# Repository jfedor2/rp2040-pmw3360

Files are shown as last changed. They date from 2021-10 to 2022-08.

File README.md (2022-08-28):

# RP2040+PMW3360

This repository contains design files and code for a PCB carrying Raspberry Pi's RP2040 chip and the PixArt PMW3360 optical mouse sensor. They can be used for rapid prototyping of USB mice and trackballs.

The files in the [fabrication](fabrication) folder can be used to order this board from JLCPCB with SMT assembly. The board you get includes everything except the sensor. If some of the specific components are out of stock, try to find an equivalent with the same package and parameters.

The sensor chip should be soldered on the bottom side (the opposite side from all the other components). The dot marks pin 1. The optic goes on the top side.

If you're looking for a convenient way of mounting mouse button switches in a case, perhaps [this repository](https://github.com/jfedor2/mouse-switch-mount-pcb) will be of use.

Examples of devices made using this board:

* [Trackball 7](https://www.prusaprinters.org/prints/83631-trackball-7)
* [Trackball 8](https://www.prusaprinters.org/prints/84148-trackball-8)
* [Spherical trackball](https://www.prusaprinters.org/prints/85053-spherical-trackball)
* [Two-ball trackball](https://github.com/jfedor2/two-ball-trackball)
* [Mouse 1](https://www.prusaprinters.org/prints/87379-mouse-1)
* [Mouse 2](https://www.prusaprinters.org/prints/88403-mouse-2)
* [Trackball with twist-to-scroll](https://github.com/jfedor2/twist-to-scroll-trackball)
* [Trackball with scroll ring](https://github.com/jfedor2/scroll-ring-trackball)
* [Mouse 4](https://www.prusaprinters.org/prints/127451-mouse-4)
* [Trackball 15](https://www.prusaprinters.org/prints/131450-trackball-15), [15b/c](https://www.printables.com/model/263616-trackball-15bc), [15d/e](https://www.printables.com/model/267954-trackball-15de)

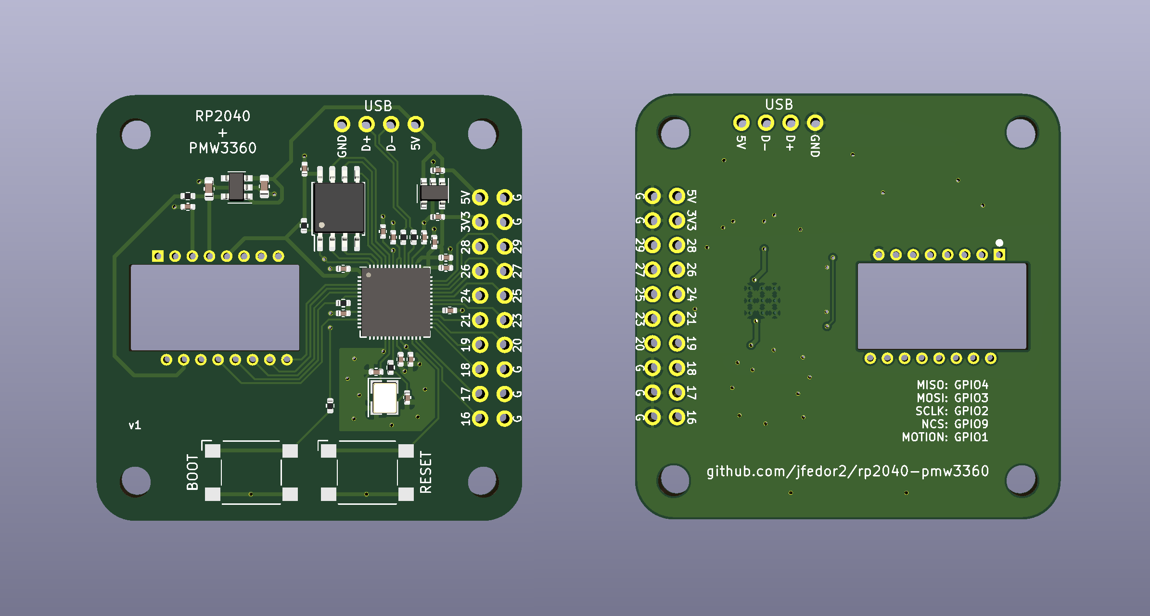
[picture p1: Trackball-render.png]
PCB render


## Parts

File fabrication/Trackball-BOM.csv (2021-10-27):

Comment | Designator | Footprint | LCSC
0.1u | C11 | Capacitor_SMD:C_0603_1608Metric | C14663
1u | C12 | Capacitor_SMD:C_0603_1608Metric | C15849
4.7u | C14 | Capacitor_SMD:C_0402_1005Metric | C23733
1u | C10,C13,C15,C16 | Capacitor_SMD:C_0402_1005Metric | C52923
30p | C18,C19 | Capacitor_SMD:C_0402_1005Metric | C1570
100n | C1,C2,C3,C4,C5,C6,C7,C8,C9,C17 | Capacitor_SMD:C_0402_1005Metric | C1525
MountingHole | H1,H2,H3,H4 | MountingHole:MountingHole_3.2mm_M3
Conn_01x04 | J1 | Connector_PinHeader_2.54mm:PinHeader_1x04_P2.54mm_Vertical
Conn_02x10_Odd_Even | J2 | Connector_PinHeader_2.54mm:PinHeader_2x10_P2.54mm_Vertical
39 | R1 | Resistor_SMD:R_0402_1005Metric | C25110
27 | R3,R4 | Resistor_SMD:R_0402_1005Metric | C138021
10k | R2,R5 | Resistor_SMD:R_0402_1005Metric | C25744
1k | R6,R7 | Resistor_SMD:R_0402_1005Metric | C11702
SW_Push | SW1,SW2 | Button_Switch_SMD:SW_SPST_Omron_B3FS-100xP | C271750
TCR2EF19 | U1 | Package_TO_SOT_SMD:SOT-23-5 | C146366
PMW3360 | U2 | PMW3360:PMW3360
RP2040 | U3 | RP2040:RP2040-QFN-56 | C2040
TLV73333PDBV | U4 | Package_TO_SOT_SMD:SOT-23-5 | C134139
W25Q128JVS | U5 | Package_SO:SOIC-8_5.23x5.23mm_P1.27mm | C97521
Crystal_GND24 | Y1 | Crystal:Crystal_SMD_3225-4Pin_3.2x2.5mm | C9002

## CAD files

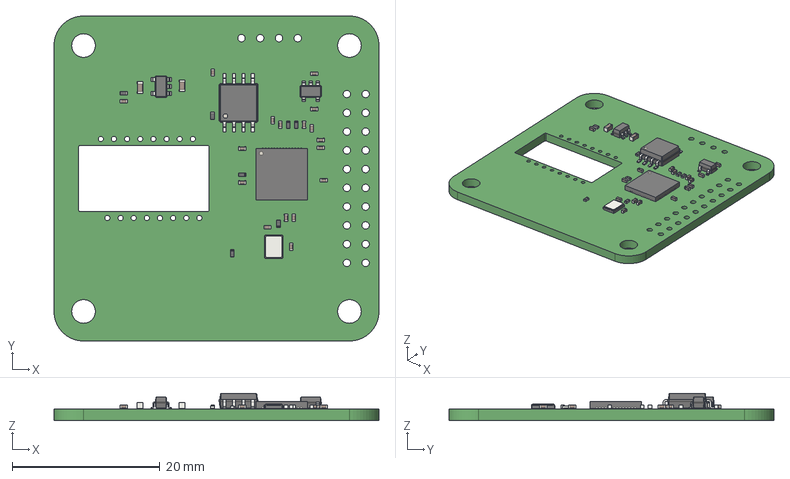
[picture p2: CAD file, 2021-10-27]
Trackball.step
44.0 x 44.0 x 3.71 mm

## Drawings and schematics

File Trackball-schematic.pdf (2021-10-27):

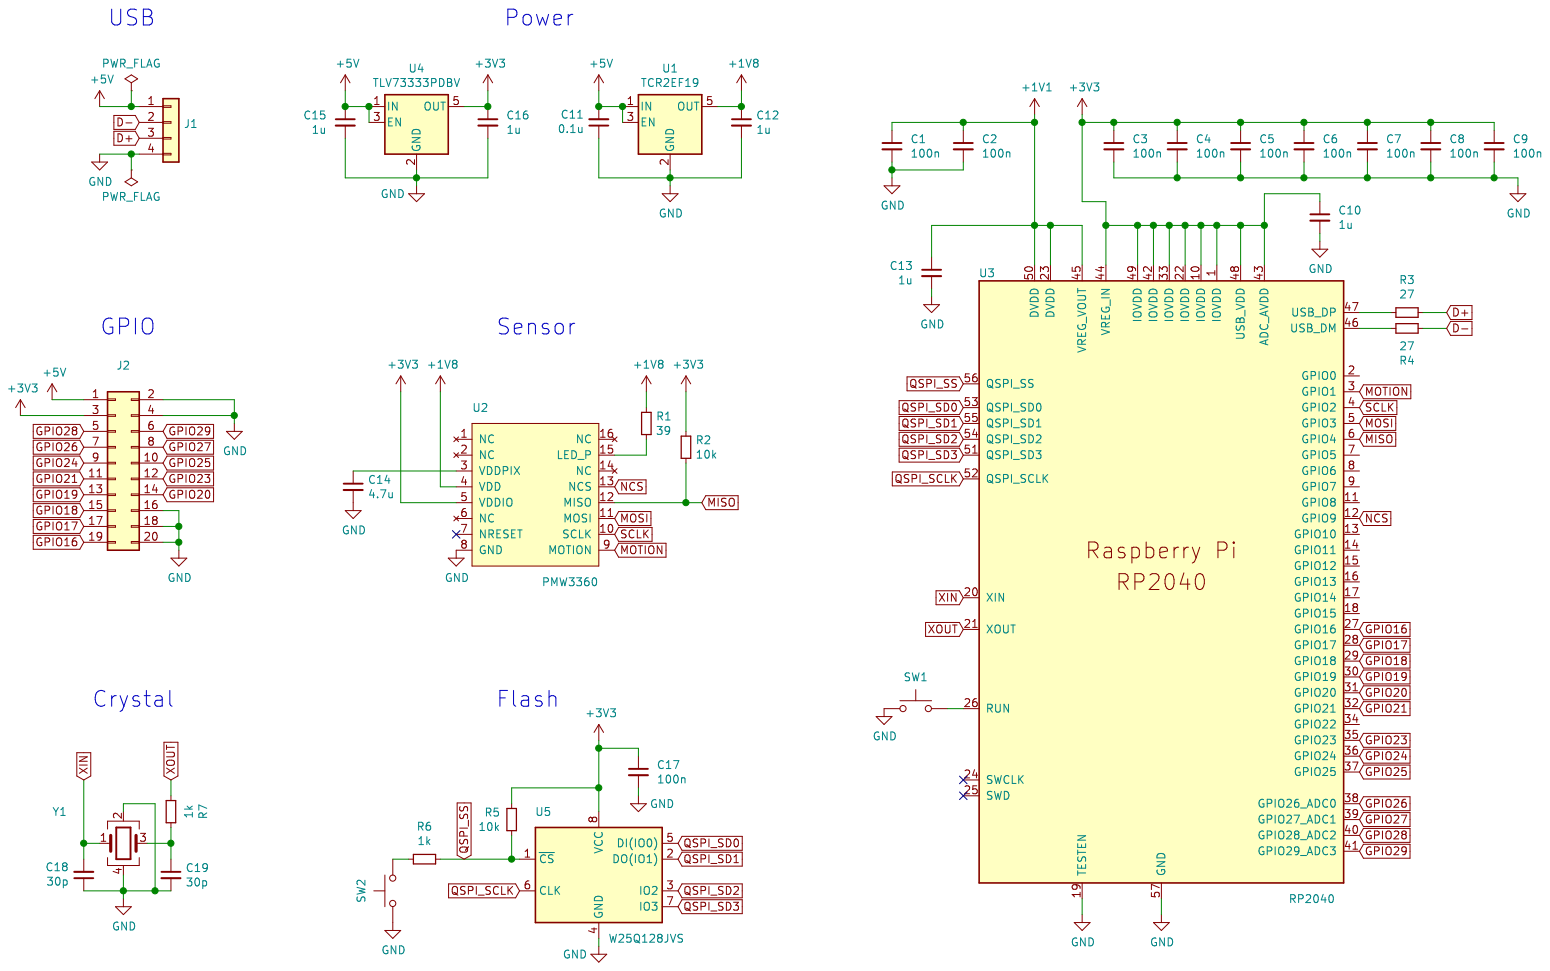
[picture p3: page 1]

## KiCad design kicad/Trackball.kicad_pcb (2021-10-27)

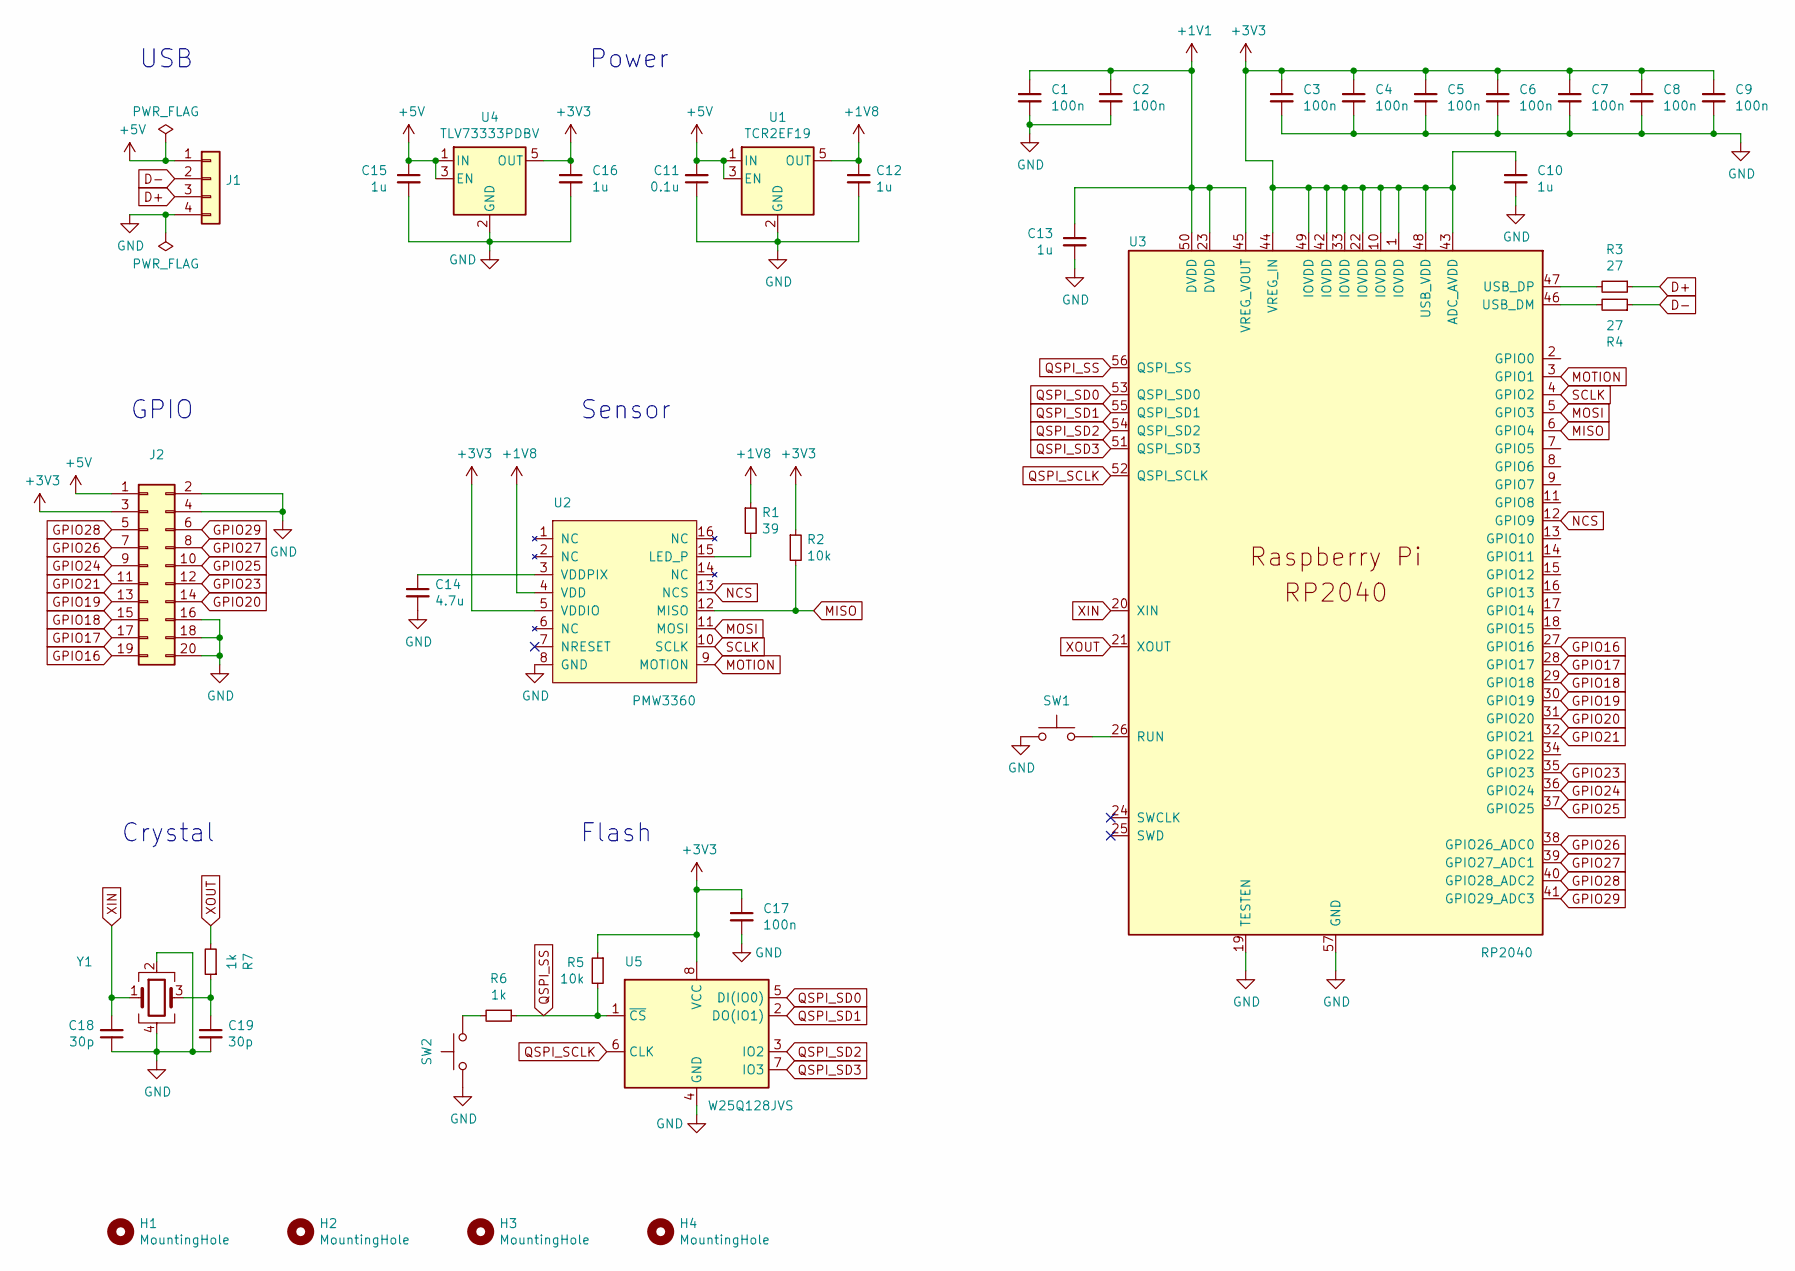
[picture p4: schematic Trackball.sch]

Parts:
C1, C2, C3, C4, C5, C6, C7, C8, C9, C17: 100n; C_0402_1005Metric; LCSC C1525
C10, C13, C15, C16: 1u; C_0402_1005Metric; LCSC C52923
C11: 0.1u; C_0603_1608Metric; LCSC C14663
C12: 1u; C_0603_1608Metric; LCSC C15849
C14: 4.7u; C_0402_1005Metric; LCSC C23733
C18, C19: 30p; C_0402_1005Metric; LCSC C1570
H1, H2, H3, H4: MountingHole; MountingHole_3.2mm_M3
J1: Conn_01x04; PinHeader_1x04_P2.54mm_Vertical
J2: Conn_02x10_Odd_Even; PinHeader_2x10_P2.54mm_Vertical
R1: 39; R_0402_1005Metric; LCSC C25110
R2, R5: 10k; R_0402_1005Metric; LCSC C25744
R3, R4: 27; R_0402_1005Metric; LCSC C138021
R6, R7: 1k; R_0402_1005Metric; LCSC C11702
SW1, SW2: SW_Push; SW_SPST_Omron_B3FS-100xP; LCSC C271750
U1: TCR2EF19; SOT-23-5; LCSC C146366
U2: PMW3360
U3: RP2040; RP2040-QFN-56; LCSC C2040
U4: TLV73333PDBV; SOT-23-5; LCSC C134139
U5: W25Q128JVS; SOIC-8_5.23x5.23mm_P1.27mm; LCSC C97521
Y1: Crystal_GND24; Crystal_SMD_3225-4Pin_3.2x2.5mm; LCSC C9002

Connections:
+1V1: C1.1, C2.1, C13.1, U3.23 (DVDD), U3.45 (VREG_VOUT), U3.50 (DVDD)
+1V8: C12.1, R1.1, U1.5 (OUT), U2.4 (VDD)
+3V3: C3.1, C4.1, C5.1, C6.1, C7.1, C8.1, C9.1, C10.1, C16.1, C17.1, J2.3, R2.1, R5.1, U2.5 (VDDIO), U3.1 (IOVDD), U3.10 (IOVDD), U3.22 (IOVDD), U3.33 (IOVDD), U3.42 (IOVDD), U3.43 (ADC_AVDD), U3.44 (VREG_IN), U3.48 (USB_VDD), U3.49 (IOVDD), U4.5 (OUT), U5.8 (VCC)
+5V: C11.2, C15.1, J1.1, J2.1, U1.1 (IN), U1.3 (EN), U4.1 (IN), U4.3 (EN)
D+: J1.3, R3.1
D-: J1.2, R4.1
GND: C1.2, C2.2, C3.2, C4.2, C5.2, C6.2, C7.2, C8.2, C9.2, C10.2, C11.1, C12.2, C13.2, C14.2, C15.2, C16.2, C17.2, C18.1, C19.2, J1.4, J2.2, J2.4, J2.16, J2.18, J2.20, SW1.1, SW2.1, U1.2 (GND), U2.8 (GND), U3.19 (TESTEN), U3.57 (GND), U4.2 (GND), U5.4 (GND), Y1.2, Y1.4
GPIO16: J2.19, U3.27 (GPIO16)
GPIO17: J2.17, U3.28 (GPIO17)
GPIO18: J2.15, U3.29 (GPIO18)
GPIO19: J2.13, U3.30 (GPIO19)
GPIO20: J2.14, U3.31 (GPIO20)
GPIO21: J2.11, U3.32 (GPIO21)
GPIO23: J2.12, U3.35 (GPIO23)
GPIO24: J2.9, U3.36 (GPIO24)
GPIO25: J2.10, U3.37 (GPIO25)
GPIO26: J2.7, U3.38 (GPIO26_ADC0)
GPIO27: J2.8, U3.39 (GPIO27_ADC1)
GPIO28: J2.5, U3.40 (GPIO28_ADC2)
GPIO29: J2.6, U3.41 (GPIO29_ADC3)
MISO: R2.2, U2.12 (MISO), U3.6 (GPIO4)
MOSI: U2.11 (MOSI), U3.5 (GPIO3)
MOTION: U2.9 (MOTION), U3.3 (GPIO1)
NCS: U2.13 (NCS), U3.12 (GPIO9)
unnamed: C14.1, U2.3 (VDDPIX)
unnamed: C19.1, R7.1, Y1.3
unnamed: R1.2, U2.15 (LED_P)
unnamed: R3.2, U3.47 (USB_DP)
unnamed: R4.2, U3.46 (USB_DM)
unnamed: R6.2, SW2.2
unnamed: SW1.2, U3.26 (RUN)
QSPI_SCLK: U3.52 (QSPI_SCLK), U5.6 (CLK)
QSPI_SD0: U3.53 (QSPI_SD0), U5.5 (DI(IO0))
QSPI_SD1: U3.55 (QSPI_SD1), U5.2 (DO(IO1))
QSPI_SD2: U3.54 (QSPI_SD2), U5.3 (IO2)
QSPI_SD3: U3.51 (QSPI_SD3), U5.7 (IO3)
QSPI_SS: R5.2, R6.1, U3.56 (QSPI_SS), U5.1 (~CS)
SCLK: U2.10 (SCLK), U3.4 (GPIO2)
XIN: C18.2, U3.20 (XIN), Y1.1
XOUT: R7.2, U3.21 (XOUT)

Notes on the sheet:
Crystal
Power
USB
Flash
GPIO
Sensor

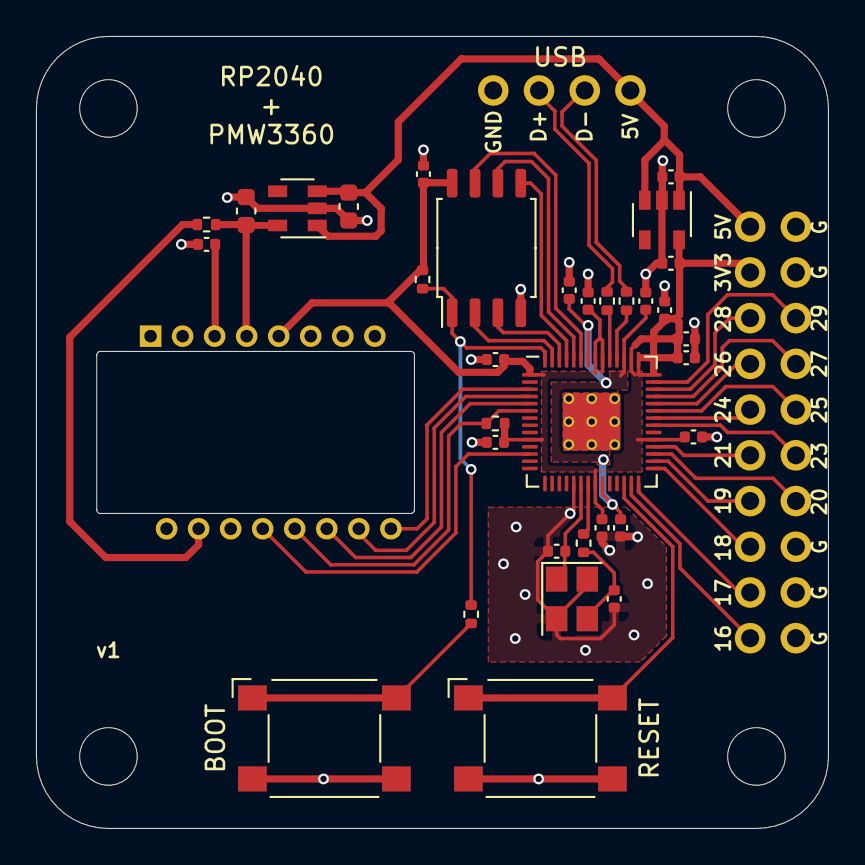
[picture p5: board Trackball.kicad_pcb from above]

Board: 2 copper layers, 44.0 x 44.0 mm, 40 parts (1 on the bottom side), 40 nets.

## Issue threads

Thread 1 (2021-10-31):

A few parts appear to be in the wrong orientation for pcba

mrlinuxfish, 2021-10-31:
When I try to order from jlcpcb, a few of the parts look like they're loading in the assembly the wrong way around

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

jfedor2, 2021-10-31:
Yeah, that's normal with files exported from KiCad. I guess there's more than one convention when it comes to the part orientation and JLCPCB uses a different one. Might be worth fixing, but it's not a problem when ordering PCBs from them (I've done it with these exact files). What happens is a human looks at the files and fixes the orientations before the PCBs are fabricated.

mrlinuxfish, 2021-10-31:
Awesome, as long as they get produced correctly there shouldn't be any problem

Closed 2021-10-31.

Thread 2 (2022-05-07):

add pullup resistors to increase switch life.

itsnoteasy, 2022-05-07:
I think that you could add a 3.3k pullup to 3.3v on each button header. this would prevent the double click bug from occuirng by providing at least 1milliamp wetting current to blow through the oxide on the switch. this is specified in the omron datasheet as required to ensure reliable operation.

there's a boring video here about it. https://www.youtube.com/watch?v=v5BhECVlKJA

Closed 2022-05-16.

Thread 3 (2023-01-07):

cheaper assembly  suggestion

itsnoteasy, 2023-01-07:
i'm about to order this but was horrified at the expense of the extended components which require adding a reel for a fee of around 6 euro per reel last time i checked. the csv and bom file generation was beyond me so i'm gonna put up with it. here's a few suggestions anyway.

replace r1 39 ohm resistor with a pair of resistors 49.9ohm and 180ohm in parallel for 39.3ohm these can be sourced in 0603 size.
likewise replace r3 and r4 with a larger size.
remove sw1 and sw2, these can be hand soldered.
I have edited the bom and csv of the last two and shaved 5 euro off my order. i cannot easily change the 39 ohm resistor.
i won't complain about the voltage regulators because they are an ephemeral purchase, but come on, 5 euro for a resistor is far too expensive.

itsnoteasy, 2023-02-16:
If you like then you can break out GPIO0 beside GPIO1(motion). this would allow the pcb to be reused as a hid-remapper, although the existing pcb should be able to make a dual rp2040 version.

jfedor2, 2023-02-18:
You should be able to use the board for HID Remapper as is, the pins used for the USB interface are configurable. You'd have to recompile the firmware.

itsnoteasy, 2023-02-18:
I figured as much but i made this issue as a way to track improvements if anyone was to make another version down the line.

Closed 2023-02-18.

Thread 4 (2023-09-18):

pico/time.h missing in pmw3360.c

FredNov, 2023-09-18:
Tried to build the code and got a warning
warning: implicit declaration of function 'sleep_us'

It seems like you need to include in pmw3360.c
#include <pico/time.h>

BTW Really great project

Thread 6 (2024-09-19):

Flashing Instructions

dahmwern, 2024-09-19:
Can you provide some flashing instructions for the PCB and sensor? I'm seeing multiple sets of .c and .h files. It would be helpful if you could shed some light into what needs to be flashed or configured here. Any help would be greatly appreciated!

My PCB is being assembled now and trackball housing design is being finalized before printing.

jfedor2, 2024-09-19:
Press and hold the BOOT button and while holding it, press and release the RESET button.

A drive named "RPI-RP2" will appear on your computer. Copy the UF2 file to it.

dahmwern, 2024-09-20:
I spent too much time looking at the code files, and missed the .uf2! Thanks!

Closed 2024-09-20.

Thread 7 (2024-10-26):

how to adjust lift off distance?

dahmwern, 2024-10-26:
Can you provide guidance on the correct way to adjust lift off distance in the code?

jfedor2, 2024-10-26:
From what I can see in the datasheet you can choose between 2 and 3 mm by writing those values to register Lift_Config (0x63).

There's also some calibration procedure, but I never tried it.

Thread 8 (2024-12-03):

Mousebuttons not recognized for libinput autoscroll binding.

slm85kbh, 2024-12-03:
Activating "Press left and right buttons for middle-click" for autoscrolling in libinput (KDE 6, Arch Linux) does not work for me.
It works on my regular Logitech MX Master 2S.

Both buttons work as they should as left/right buttons otherwise.
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

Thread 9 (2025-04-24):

Does this PCB support QMK firmware?

619frank, 2025-04-24:

jfedor2, 2025-04-24:
I haven't tried, but if QMK runs on RP2040 and supports the PMW3360 sensor then I don't see why it wouldn't work.

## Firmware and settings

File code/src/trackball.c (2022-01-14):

/* 
 * The MIT License (MIT)
 *
 * Copyright (c) 2021 Jacek Fedorynski
 * Copyright (c) 2019 Ha Thach (tinyusb.org)
 *
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
 */

#include <stdlib.h>
#include <stdio.h>
#include <string.h>

#include "bsp/board.h"
#include "tusb.h"

#include "pico/stdlib.h"

#include "hardware/gpio.h"

#include "pmw3360.h"

#define PIN_LMB 16
#define PIN_RMB 17

// These IDs are bogus. If you want to distribute any hardware using this,
// you will have to get real ones.
#define USB_VID 0xCAFE
#define USB_PID 0xBABA

tusb_desc_device_t const desc_device = {
    .bLength = sizeof(tusb_desc_device_t),
    .bDescriptorType = TUSB_DESC_DEVICE,
    .bcdUSB = 0x0200,
    .bDeviceClass = 0x00,
    .bDeviceSubClass = 0x00,
    .bDeviceProtocol = 0x00,
    .bMaxPacketSize0 = CFG_TUD_ENDPOINT0_SIZE,

    .idVendor = USB_VID,
    .idProduct = USB_PID,
    .bcdDevice = 0x0100,

    .iManufacturer = 0x01,
    .iProduct = 0x02,
    .iSerialNumber = 0x00,

    .bNumConfigurations = 0x01
};

uint8_t const desc_hid_report[] = {
    0x05, 0x01,                 // USAGE_PAGE (Generic Desktop)
    0x09, 0x02,                 // USAGE (Mouse)
    0xa1, 0x01,                 // COLLECTION (Application)
    0x09, 0x01,                 //   USAGE (Pointer)
    0xA1, 0x00,                 //   COLLECTION (Physical)
//  0x85, 0x01,                 //     REPORT_ID (1)
    0x05, 0x09,                 //     USAGE_PAGE (Button)
    0x19, 0x01,                 //     USAGE_MINIMUM (1)
    0x29, 0x03,                 //     USAGE_MAXIMUM (3)
    0x15, 0x00,                 //     LOGICAL_MINIMUM (0)
    0x25, 0x01,                 //     LOGICAL_MAXIMUM (1)
    0x95, 0x03,                 //     REPORT_COUNT (3)
    0x75, 0x01,                 //     REPORT_SIZE (1)
    0x81, 0x02,                 //     INPUT (Data,Var,Abs)
    0x95, 0x01,                 //     REPORT_COUNT (1)
    0x75, 0x05,                 //     REPORT_SIZE (5)
    0x81, 0x03,                 //     INPUT (Const,Var,Abs)
    0x05, 0x01,                 //     USAGE_PAGE (Generic Desktop)
    0x09, 0x30,                 //     USAGE (X)
    0x09, 0x31,                 //     USAGE (Y)
    0x16, 0x00, 0x80,           //     LOGICAL_MINIMUM(-32768)
    0x26, 0xff, 0x7f,           //     LOGICAL_MAXIMUM(32767)
    0x75, 0x10,                 //     REPORT_SIZE (16)
    0x95, 0x02,                 //     REPORT_COUNT (2)
    0x81, 0x06,                 //     INPUT (Data,Var,Rel)
    0xC0,                       //   END_COLLECTION
    0xC0,                       // END COLLECTION
};

#define CONFIG_TOTAL_LEN (TUD_CONFIG_DESC_LEN + TUD_HID_DESC_LEN)
#define EPNUM_HID 0x81

uint8_t const desc_configuration[] = {
    // Config number, interface count, string index, total length, attribute, power in mA
    TUD_CONFIG_DESCRIPTOR(1, 1, 0, CONFIG_TOTAL_LEN, 0, 100),

    // Interface number, string index, protocol, report descriptor len, EP In address, size & polling interval
    TUD_HID_DESCRIPTOR(0, 0, HID_ITF_PROTOCOL_NONE, sizeof(desc_hid_report), EPNUM_HID, CFG_TUD_HID_EP_BUFSIZE, 1)
};

char const *string_desc_arr[] = {
    (const char[]) {0x09, 0x04},        // 0: is supported language is English (0x0409)
    "Trackball",                // 1: Manufacturer
    "Trackball",                // 2: Product
};

// HID report
typedef struct __attribute__ ((packed)) {
    uint8_t buttons;
    int16_t dx;
    int16_t dy;
} hid_report_t;

hid_report_t report;

void hid_task(void) {
    int16_t dx;
    int16_t dy;

    if (!tud_hid_ready()) {
        return;
    }

    pmw3360_get_deltas(&dx, &dy);

    report.dx = dx;
    report.dy = -dy;

    report.buttons = !gpio_get(PIN_LMB) ? 0x01 : 0x00 | !gpio_get(PIN_RMB) ? 0x02 : 0x00;

    tud_hid_report(0, &report, sizeof(report));
}

void pin_init(uint pin) {
    gpio_init(pin);
    gpio_set_dir(pin, GPIO_IN);
    gpio_pull_up(pin);
}

void pins_init(void) {
    pin_init(PIN_LMB);
    pin_init(PIN_RMB);
}

void report_init(void) {
    memset(&report, 0, sizeof(report));
}

int main(void) {
    stdio_init_all();
    board_init();
    pins_init();
    pmw3360_init();
    report_init();
    tusb_init();

    pmw3360_set_cpi(800);

    while (1) {
        tud_task();             // tinyusb device task
        hid_task();
    }

    return 0;
}

// Invoked when received GET DEVICE DESCRIPTOR
// Application return pointer to descriptor
uint8_t const *tud_descriptor_device_cb(void) {
    return (uint8_t const *) &desc_device;
}

// Invoked when received GET HID REPORT DESCRIPTOR
// Application return pointer to descriptor
// Descriptor contents must exist long enough for transfer to complete
uint8_t const *tud_hid_descriptor_report_cb(uint8_t itf) {
    return desc_hid_report;
}

// Invoked when received GET_REPORT control request
// Application must fill buffer report's content and return its length.
// Return zero will cause the stack to STALL request
uint16_t tud_hid_get_report_cb(uint8_t itf, uint8_t report_id, hid_report_type_t report_type, uint8_t * buffer, uint16_t reqlen) {
    return 0;
}

// Invoked when received SET_REPORT control request or
// received data on OUT endpoint ( Report ID = 0, Type = 0 )
void tud_hid_set_report_cb(uint8_t itf, uint8_t report_id, hid_report_type_t report_type, uint8_t const *buffer, uint16_t bufsize) {
}

// Invoked when received GET CONFIGURATION DESCRIPTOR
// Application return pointer to descriptor
// Descriptor contents must exist long enough for transfer to complete
uint8_t const *tud_descriptor_configuration_cb(uint8_t index) {
    return desc_configuration;
}

static uint16_t _desc_str[32];

// Invoked when received GET STRING DESCRIPTOR request
// Application return pointer to descriptor, whose contents must exist long enough for transfer to complete
uint16_t const *tud_descriptor_string_cb(uint8_t index, uint16_t langid) {
    uint8_t chr_count;

    if (index == 0) {
        memcpy(&_desc_str[1], string_desc_arr[0], 2);
        chr_count = 1;
    } else {
        // Note: the 0xEE index string is a Microsoft OS 1.0 Descriptors.
        // https://docs.microsoft.com/en-us/windows-hardware/drivers/usbcon/microsoft-defined-usb-descriptors

        if (!(index < sizeof(string_desc_arr) / sizeof(string_desc_arr[0])))
            return NULL;

        const char *str = string_desc_arr[index];

        // Cap at max char
        chr_count = strlen(str);
        if (chr_count > 31)
            chr_count = 31;

        // Convert ASCII string into UTF-16
        for (uint8_t i = 0; i < chr_count; i++) {
            _desc_str[1 + i] = str[i];
        }
    }

    // first byte is length (including header), second byte is string type
    _desc_str[0] = (TUSB_DESC_STRING << 8) | (2 * chr_count + 2);

    return _desc_str;
}

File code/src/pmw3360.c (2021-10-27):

// derived from https://github.com/mrjohnk/PMW3360DM-T2QU

#include "hardware/gpio.h"
#include "hardware/spi.h"

#include "srom.h"

#define SPI_PORT spi0

#define PIN_MISO 4
#define PIN_CS   9
#define PIN_SCK  2
#define PIN_MOSI 3

// Registers
#define Product_ID  0x00
#define Revision_ID 0x01
#define Motion  0x02
#define Delta_X_L 0x03
#define Delta_X_H 0x04
#define Delta_Y_L 0x05
#define Delta_Y_H 0x06
#define SQUAL 0x07
#define Raw_Data_Sum  0x08
#define Maximum_Raw_data  0x09
#define Minimum_Raw_data  0x0A
#define Shutter_Lower 0x0B
#define Shutter_Upper 0x0C
#define Control 0x0D
#define Config1 0x0F
#define Config2 0x10
#define Angle_Tune  0x11
#define Frame_Capture 0x12
#define SROM_Enable 0x13
#define Run_Downshift 0x14
#define Rest1_Rate_Lower  0x15
#define Rest1_Rate_Upper  0x16
#define Rest1_Downshift 0x17
#define Rest2_Rate_Lower  0x18
#define Rest2_Rate_Upper  0x19
#define Rest2_Downshift 0x1A
#define Rest3_Rate_Lower  0x1B
#define Rest3_Rate_Upper  0x1C
#define Observation 0x24
#define Data_Out_Lower  0x25
#define Data_Out_Upper  0x26
#define Raw_Data_Dump 0x29
#define SROM_ID 0x2A
#define Min_SQ_Run  0x2B
#define Raw_Data_Threshold  0x2C
#define Config5 0x2F
#define Power_Up_Reset  0x3A
#define Shutdown  0x3B
#define Inverse_Product_ID  0x3F
#define LiftCutoff_Tune3  0x41
#define Angle_Snap  0x42
#define LiftCutoff_Tune1  0x4A
#define Motion_Burst  0x50
#define LiftCutoff_Tune_Timeout 0x58
#define LiftCutoff_Tune_Min_Length  0x5A
#define SROM_Load_Burst 0x62
#define Lift_Config 0x63
#define Raw_Data_Burst  0x64
#define LiftCutoff_Tune2  0x65

void cs_select() {
    asm volatile ("nop \n nop \n nop");
    gpio_put(PIN_CS, 0);        // Active low
    asm volatile ("nop \n nop \n nop");
}

void cs_deselect() {
    asm volatile ("nop \n nop \n nop");
    gpio_put(PIN_CS, 1);
    asm volatile ("nop \n nop \n nop");
}

uint8_t read_register(uint8_t reg_addr) {
    cs_select();

    // send adress of the register, with MSBit = 0 to indicate it's a read
    uint8_t x = reg_addr & 0x7f;
    spi_write_blocking(SPI_PORT, &x, 1);
    sleep_us(100);              // tSRAD
    // read data
    uint8_t data;
    spi_read_blocking(SPI_PORT, 0, &data, 1);

    sleep_us(1);                // tSCLK-NCS for read operation is 120ns
    cs_deselect();
    sleep_us(19);               // tSRW/tSRR (=20us) minus tSCLK-NCS

    return data;
}

void write_register(uint8_t reg_addr, uint8_t data) {
    cs_select();

    // send adress of the register, with MSBit = 1 to indicate it's a write
    uint8_t x = reg_addr | 0x80;
    spi_write_blocking(SPI_PORT, &x, 1);
    // send data
    spi_write_blocking(SPI_PORT, &data, 1);

    sleep_us(20);               // tSCLK-NCS for write operation
    cs_deselect();
    sleep_us(100);              // tSWW/tSWR (=120us) minus tSCLK-NCS. Could be shortened, but is looks like a safe lower bound 
}

void upload_firmware() {
    // send the firmware to the chip, cf p.18 of the datasheet

    // Write 0 to Rest_En bit of Config2 register to disable Rest mode.
    write_register(Config2, 0x20);

    // write 0x1d in SROM_enable reg for initializing
    write_register(SROM_Enable, 0x1d);

    // wait for more than one frame period
    sleep_ms(10);               // assume that the frame rate is as low as 100fps... even if it should never be that low

    // write 0x18 to SROM_enable to start SROM download
    write_register(SROM_Enable, 0x18);

    // write the SROM file (=firmware data) 
    cs_select();
    uint8_t data = SROM_Load_Burst | 0x80; // write burst destination adress
    spi_write_blocking(SPI_PORT, &data, 1);
    sleep_us(15);

    // send all bytes of the firmware
    for (int i = 0; i < firmware_length; i++) {
        spi_write_blocking(SPI_PORT, &(firmware_data[i]), 1);
        sleep_us(15);
    }

    // Read the SROM_ID register to verify the ID before any other register reads or writes.
    read_register(SROM_ID);

    // Write 0x00 to Config2 register for wired mouse or 0x20 for wireless mouse design.
    write_register(Config2, 0x00);

    // set initial CPI resolution
    write_register(Config1, 0x15);

    cs_deselect();
}

void perform_startup(void) {
    cs_deselect();              // ensure that the serial port is reset
    cs_select();                // ensure that the serial port is reset
    cs_deselect();              // ensure that the serial port is reset
    write_register(Power_Up_Reset, 0x5a);       // force reset
    sleep_ms(50);               // wait for it to reboot
    // read registers 0x02 to 0x06 (and discard the data)
    read_register(Motion);
    read_register(Delta_X_L);
    read_register(Delta_X_H);
    read_register(Delta_Y_L);
    read_register(Delta_Y_H);
    // upload the firmware
    upload_firmware();
    sleep_ms(10);
}

void pmw3360_set_cpi(unsigned int cpi) {
    int cpival = (cpi / 100) - 1;
    cs_select();
    write_register(Config1, cpival);
    cs_deselect();
}

void pmw3360_get_deltas(int16_t * dx, int16_t * dy) {
    // write 0x01 to Motion register and read from it to freeze the motion values and make them available
    write_register(Motion, 0x01);
    read_register(Motion);

    *dx = (int16_t) (read_register(Delta_X_H) << 8 | read_register(Delta_X_L));
    *dy = (int16_t) (read_register(Delta_Y_H) << 8 | read_register(Delta_Y_L));
}

void pmw3360_init() {
    gpio_set_function(PIN_MISO, GPIO_FUNC_SPI);
    gpio_set_function(PIN_SCK, GPIO_FUNC_SPI);
    gpio_set_function(PIN_MOSI, GPIO_FUNC_SPI);

    gpio_init(PIN_CS);
    gpio_set_dir(PIN_CS, GPIO_OUT);
    gpio_put(PIN_CS, 1);

    spi_init(SPI_PORT, 500000);
    spi_set_format(SPI_PORT, 8, 1, 1, SPI_MSB_FIRST);

    perform_startup();
}

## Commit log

2021-10-30 Add another example device
2021-11-03 One more example device
2021-11-17 Yet another example device
2021-11-19 And one more example device
2021-12-15 Add two more example devices
2022-01-14 Don't fetch sensor data if !tud_hid_ready()
    Moves the tud_hid_ready() check to the beginning of the hid_task()
    function, so that we don't drop sensor readings if USB is not ready.
    With this change, the sensor keeps accumulating the deltas until we're
    ready for them.
2022-01-31 Add another trackball to example devices
2022-01-31 Add another mouse to example devices
2022-08-28 Add more variants to example device list
